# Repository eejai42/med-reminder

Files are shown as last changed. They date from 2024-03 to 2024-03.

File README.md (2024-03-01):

# Physical Med Reminder

The Physical Med Reminder is a novel, Arduino-assisted pillbox solution crafted to simplify the management of a twice-daily medication schedule without necessitating a complex user interface. This intuitive device is designed to learn the user's medication times through their actions, making it an ideal choice for individuals looking for an efficient and user-friendly medication management system.

## Project Overview

- **Name:** physical-med-reminder
- **Description:** A user-friendly, Arduino-assisted physical pillbox that manages a twice-daily medication schedule. It learns the user's medication times based on their initial actions after power-up, eliminating the need for a complex user interface.
- **Usage:**
  - **Box 1:** For Monday morning through Thursday morning doses.
  - **Box 2:** For Thursday evening through Sunday evening doses.
  - **Setting Reminder Times:** Plug in the device and take medication as normal to set the reminder schedule.

## Rules and Operation

### Setup

- The pillbox is organized to support a twice-daily medication regimen. Each compartment corresponds to a specific day and time (morning/evening).
- Magnets are placed in the compartments to track medication intake.

### Interaction

- The Arduino system signals when it's time to take medication through audible reminders. These reminders escalate in urgency until the medication is taken.
- The system learns the medication schedule based on user interaction after initial power-up. No further interaction is required unless there is a change in the medication schedule.

### Management

- Designed for easy setup, users fill each compartment according to their medication schedule at the beginning of the week.
- A power supply from a wall adapter ensures consistent operation, while the Arduino's internal clock maintains the time.
- To reset the schedule in the event of a power outage or medication time change, unplug the device, plug it back in, and take the pills as normal.

### Error Handling

- The device confirms learning the medication times through audible signals. Error handling informs the user of successful setup or any issues detected.

## Getting Started

This section will guide you through the initial setup and use of your Physical Med Reminder:

1. **Plug in the device** to a power source using the wall adapter.
2. **Fill the compartments** according to your weekly medication schedule. Ensure Box 1 is for morning doses (Monday to Thursday) and Box 2 for evening doses (Thursday to Sunday).
3. **Take your medication** at the usual times. The device will learn and remember these times as your medication schedule.
4. **Listen for reminders.** The device will alert you with audible reminders when it's time for your next dose.

## Support and Maintenance

For any questions, troubleshooting, or support needs, please refer to the user manual or contact our support team. Regular maintenance includes checking the power supply and ensuring the compartments are correctly filled at the start of each week.

## Conclusion

The Physical Med Reminder is more than just a pillbox; it's a comprehensive medication management system designed to adapt to your schedule, ensuring you never miss a dose again. With its simple setup and intuitive design, managing your medication has never been easier.

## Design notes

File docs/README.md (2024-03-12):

# Physical-Med-Reminder

## Project Overview

**Physical-Med-Reminder** is an innovative Arduino-assisted physical pillbox solution tailored to manage a twice-daily medication schedule efficiently. It stands out for its user-friendly design, eliminating the need for a complex interface by learning the user's medication times through their initial interactions. This project features two distinct pillboxes to cover a full week's medication regimen, leveraging Arduino technology for intelligent reminders and medication tracking.

### Description

This system is designed to simplify medication management without the need for constant reprogramming. Upon initial setup, the device learns the user's medication times based on their actions, setting up reminders accordingly. It employs a mechanical design with two separate units, each divided into seven compartments for a week's worth of medication, facilitating a straightforward morning and evening medication regimen.

### Usage

- **Box 1** is designated for Monday morning through Thursday morning doses.
- **Box 2** is used for Thursday evening through Sunday evening doses.
- Users set the reminder times by plugging in the device and taking their medication as usual. The device then schedules reminders based on these actions.

## Technical Specifications

### Wheel Configuration Overview

The system comprises two wheels (pillboxes), each divided into seven slices corresponding to days and times when medications need to be taken. These slices are equipped with magnets whose arrangements (read by hall effect sensors) serve to uniquely identify each slice, facilitating the system's ability to determine the current position and, consequently, the specific medication due for dispensing.

### Arduino Pin Configuration

The Physical-Med-Reminder system utilizes several pins on the Arduino for connecting various components such as speakers, LEDs, Hall effect sensors, and latching switches. Below is the updated pin configuration based on the latest information provided:

[Wheel and Pin Configuration Details](WheelAndPins.md)

### Time Settings
- **Day_time** and **Eve_time**: The system records the time of the first medication taken during the day and evening as the set reminder times for subsequent doses. This adaptive timing mechanism allows the system to align with the user's personal routine, ensuring medication reminders are timely and relevant.

### Binary Slice Identification
Each slice within the wheels is encoded with a binary representation, facilitating the identification process through the hall effect sensors. This coding allows the Arduino to determine not only which day's medication is due but also whether it's the day or evening dose, based on the unique binary slice ID associated with each compartment.

- **Example**: A slice with a binary code of `[0, 0, 1]` signals a specific position within the wheel, distinct from `[1, 1, 1]`, which represents a different day/time slot.

The **Movement State Machine** for the Physical-Med-Reminder project orchestrates the detection and handling of the mechanical movement of the pillbox wheels. This machine ensures the system accurately tracks the user's interaction with the pillbox, adjusting the reminder schedule accordingly. Below is an expanded and detailed explanation of each state and its role within the system.

[Movement State Machine Details](FSM.md)

### Operational Insight
This configuration ensures the Physical-Med-Reminder system can accurately track and manage the dispensing of medications throughout the week. By leveraging the binary slice IDs and the differentiation between day and evening times, the system provides a user-friendly, intuitive solution for medication adherence, minimizing the need for manual setup or frequent interaction.

## Arduino Settings

This section details the technical configuration of the Arduino hardware used in the Physical-Med-Reminder system. Understanding these settings is crucial for developers or technical users who wish to modify or further develop the system.

### Debounce Configuration

- **Wheel Turn Debounce (150 ms):** Minimizes noise or false triggers when detecting wheel rotation. It ensures that only intentional movements are registered.
- **Quick Turn Threshold (300 ms):** Differentiates between quick successive turns and slower, deliberate turns, aiding in accurately determining user interaction with the device.
- **Debounce Delay (500 ms):** Applied to all Hall effect sensors to filter out electrical noise and ensure stable readings.

### Timing

The med-reminder tracks only it's on start time, and the two pill times relative to that start time.  The actual time of day is not tracked.

[Timing Settings](Timing.md)

The **Technical Details** section outlines the hardware components and their functionalities within the Physical-Med-Reminder system. This system employs a blend of hall effect sensors, magnets, and a speaker to create a user-friendly medication management tool. Below, we delve into each component's role and how they integrate to form the operational backbone of the pillbox.

### Hardware Configuration

#### Hall Effect Sensors
- **Quantity**: 4
- **Functionality**: Hall effect sensors are crucial for detecting the presence of magnets in the pillbox slots. These sensors allow the system to identify which slot is currently positioned for dispensing medication. By reading the unique magnet configurations assigned to each slot, the system accurately tracks the user's medication schedule. This feature is key to the system's ability to learn and adapt to the user's medication-taking habits, ensuring timely reminders without the need for manual schedule inputs.

#### Magnets

- **Quantity**: 25
- 
- **Functionality**: Magnets are embedded within the pillbox slots, each arranged in a unique configuration to correspond with a specific day and time of medication. This arrangement enables the hall effect sensors to distinguish between the different slots and, by extension, the specific times medication needs to be taken. The strategic placement of these magnets is essential for the accurate identification of slots, allowing for an automated tracking system that adjusts to the user's medication regimen.

#### Speaker

- **Quantity**: 1

- **Functionality**: The speaker serves as the primary interface for auditory communication with the user. It is programmed to emit different patterns of sounds based on the system's status or required user actions. For instance:

  - **Medication Reminder**: A distinct sound pattern is played when it's time for the user to take their medication, serving as an effective reminder.
  
  - **Slot Not Advanced Warning**: If the system detects that the medication has not been taken following a reminder (i.e., the box has not been advanced to the next slot), it emits a different sound pattern to alert the user.

### Operational Integration

- **Slot Identification**: Combining the use of hall effect sensors and magnets, the system can pinpoint exactly which slot of the pillbox is ready for the user to access. This identification process is vital for maintaining an accurate medication schedule, ensuring that users are reminded only when it's time to take their medication.

- **Audible Notifications**: The speaker's role in the system extends beyond mere reminders. It confirms successful interactions (e.g., when the user advances the pillbox to the next slot) and alerts to errors or missed medication times. This auditory feedback mechanism is designed to be intuitive, minimizing the learning curve for users and enhancing the system's usability.

The design of the Physical-Med-Reminder leverages these components to create a seamless and efficient medication management experience. By intelligently combining hardware elements with sophisticated programming, the system offers a reliable solution to the challenge of medication adherence, tailored to meet the needs of individuals with various schedules and lifestyles.

## Setup and Operation

### Initial Setup

1. Fill each compartment according to the medication schedule at the beginning of the week.
2. Plug in the device and proceed to take medication as normal to set the reminder schedule.

### Daily Use

- The device signals medication times through escalating audible reminders.
- Manual rotation of the pillbox's current slot is achieved through a central button, moving to the next scheduled dose.

## Error Handling

The system provides auditory signals to confirm successful learning of medication times. It is equipped to inform the user of successful setup or detect any issues, ensuring reliable medication management.

## Maintenance and Management

Designed for easy setup and minimal maintenance, the device requires only a weekly refill and occasional reset (in case of a power outage or schedule change) by unplugging and replugging the device, then taking

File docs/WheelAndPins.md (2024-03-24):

[Full Readme](README.md)

### Pin Configuration

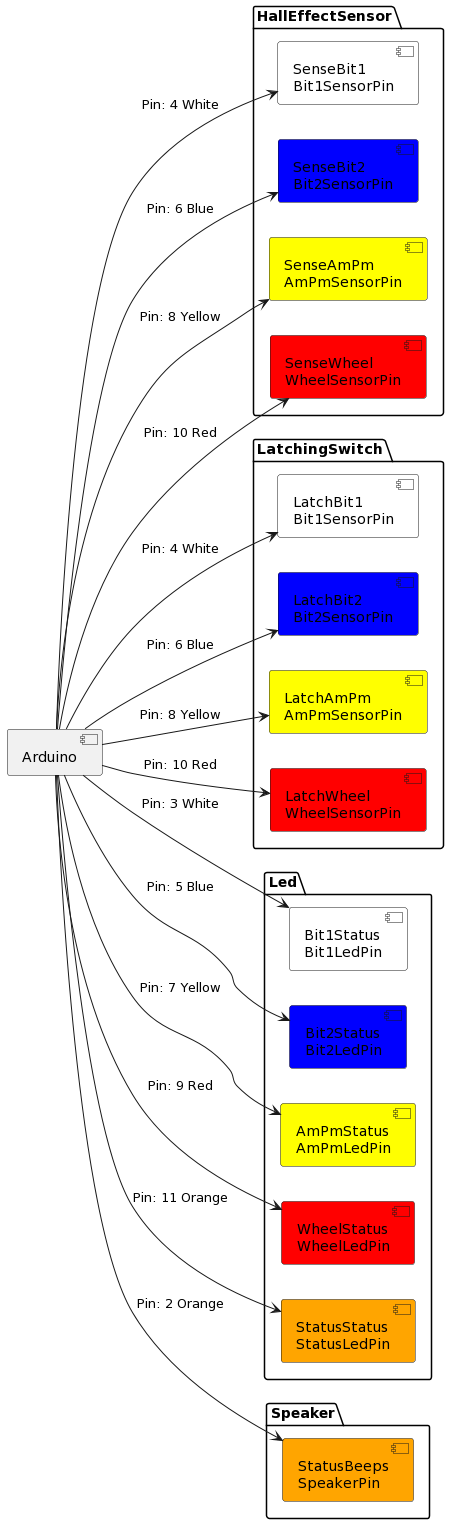
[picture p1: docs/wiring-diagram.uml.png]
Diagram


- **Speaker Pin (Pin 2)**: Utilized for status beep notifications, indicating reminders or alerts. Connected to a digital output pin on the Arduino.

#### LED Pins:
- **Bit1 Status LED (Pin 3)**: White LED for indicating Bit1 status.
- **Bit2 Status LED (Pin 5)**: Blue LED for indicating Bit2 status.
- **AM/PM Status LED (Pin 7)**: Yellow LED for differentiating between AM and PM doses.
- **Wheel Status LED (Pin 9)**: Red LED for showing the wheel's (pillbox) current position.
- **Status LED (Pin 11)**: Orange LED for general status indications.

#### Hall Effect Sensor Pins:
- **Bit1 Sensor (Pin 4)**: For sensing the position related to Bit1, utilizing two Hall effect sensors.
- **Bit2 Sensor (Pin 6)**: For sensing the position related to Bit2, also with two Hall effect sensors.
- **AM/PM Sensor (Pin 8)**: To determine the AM/PM slot, using two Hall effect sensors.
- **Wheel Sensor (Pin 10)**: For detecting the wheel's position, equipped with two Hall effect sensors.

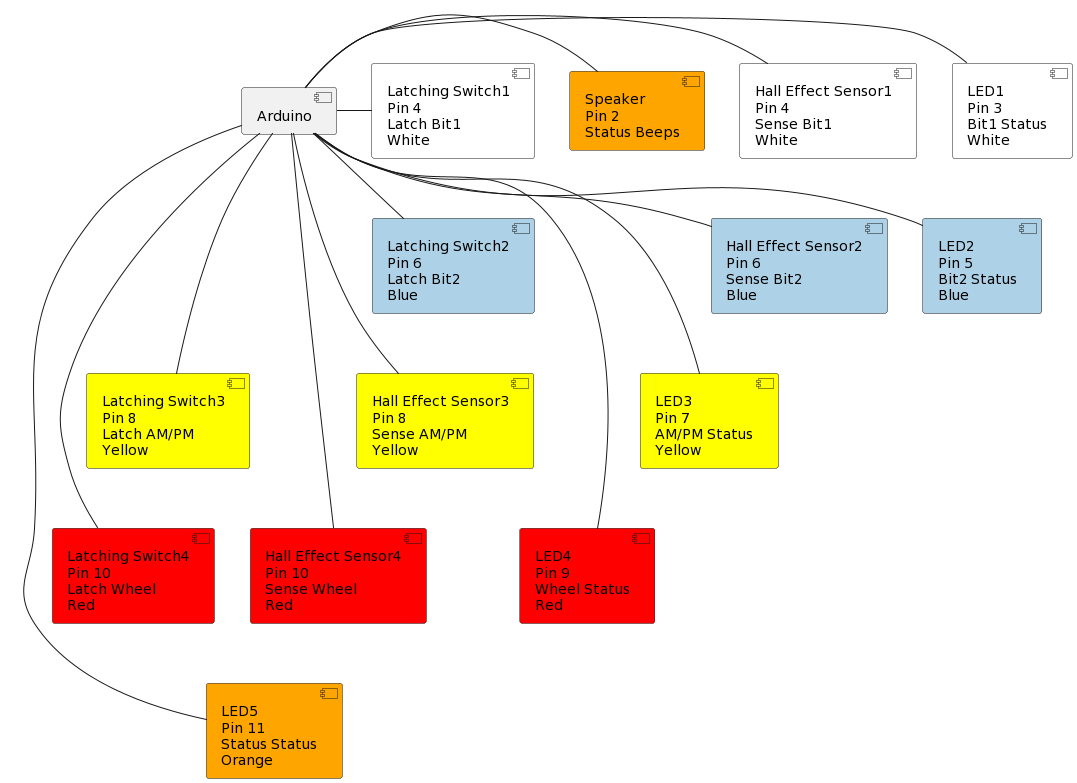
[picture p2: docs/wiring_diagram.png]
Wiring Diagram


### Wheel Details

The **Wheel Configurations** section provides detailed insights into how the Physical-Med-Reminder system organizes and identifies each compartment or "slice" of its two pillboxes, referred to as wheels. Each wheel is designed to accommodate a week's medication schedule, with unique identifiers for time of day (morning or evening) and specific days of the week. This structure is pivotal for the system's operation, ensuring precise medication dispensing and adherence to the user's schedule.

#### Wheel 1
- **Intended Use**: Covers Monday morning through Thursday morning doses.
- **Configuration**:
  - **Slices**: Each slice is designated for a specific day and either "Day" or "Eve" (evening) medication.
  - **Pill IDs**: Assigned from 1 to 7, correlating with each compartment's intended medication.
  - **Binary Slice ID**: A three-digit binary code unique to each slice, allowing the system to recognize the current compartment via hall effect sensors.

#### Wheel 2
- **Intended Use**: Utilized for Thursday evening through Sunday evening doses.
- **Configuration**:
  - The second wheel picks up where the first one leaves off, continuing with Thursday evening and ending with Sunday evening.
  - Similar to Wheel 1, each slice has a unique Pill ID and a binary code identifier. However, Wheel 2 has a distinguishing feature: a wheel sensor activated (marked as `true`) to differentiate its slices from those of Wheel 1.

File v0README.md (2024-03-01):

# Med-Reminder

Med-Reminder is a comprehensive medication reminder app for Android and iOS that helps users to never miss their medications. The app comes with unique features which include setting multiple reminders per day, a decaying back-off system that increases urgency and decreases frequency, and marking reminders as taken.

## Rules

- Set multiple reminders per day, must be marked as taken
- Unique decaying back-off system, increasing urgency, decreasing frequency
- Single quiet beep for initial reminder, auto-snooze for 10 seconds
- Initial reminder gentle, w/ increasing intensity after subsequent auto-snoozes.
- Gradually louder, but less frequent beeps following Fibonacci sequence
- Reminders not marked as 'taken' auto-snoozed
- Reminder skipped even if pill intake marked early

### Use Case 1

Imagine a person who needs to take medication every six hours. They set the first reminder for 8 am and mark it as taken. At 11 am, the second reminder goes off, and they take their pills, marking it as taken. However, at 2 pm, the third reminder goes off, but they forget to take their pills. The app auto-snoozes the reminder but then rings again after a short while, with a slightly louder beep. This continues until the user marks the reminder as "taken," ensuring that they don't miss a dose.

### Use Case 2

Consider a person who takes several medications at different times of the day. They set reminders for each of their medications, and the app reminds them accordingly. If they forget to mark a reminder as "taken," the app auto-snoozes it and reminds them again later with gradually louder and less frequent beeps, ensuring that they take all their medications on time.

## Conclusion

The Med-Alarm app ensures that users never miss taking their medications by providing multiple reminders and using a decaying back-off system that increases urgency and decreases frequency. The app also helps users keep track of their medication intake by allowing them to mark reminders as "taken." These rules help users stay on top of their medication schedules and improve their health outcomes.

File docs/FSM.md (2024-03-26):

[Full Readme](README.md)

### Movement State Machine (FSM)

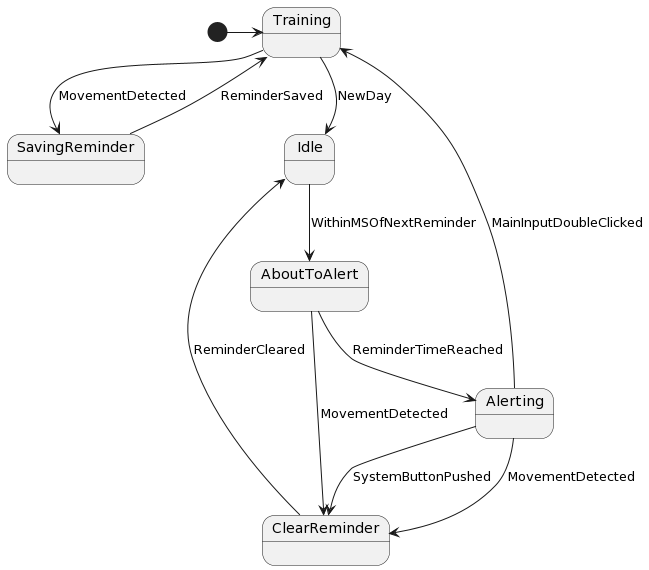
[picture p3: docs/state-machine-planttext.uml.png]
Diagram


### States and Transitions

#### 1. Training
First day - it just counts when pills are taken

 - **`Training .`**_`MovementDetected`_**`( ➡ SavingReminder )`:** 
 <span style="font-size: 1em; margin-bottom: 0.75em; color: green;">On training day, movement saves the reminder.<br /> <span>
 - **`Training .`**_`NewDay`_**`( ➡ Idle )`:** 
 <span style="font-size: 1em; margin-bottom: 0.75em; color: green;">When the first 24 hours is reached, the system stops training, and moves into the idle state.<br /> <span>
---------
 - **`SavingReminder .`**_`ReminderSaved`_**`( this )`:** 
 <span style="font-size: 0.8em; padding-bottom: 0.25em; color: darkgray;">On training day, the reminder is saved, and returns to Training.<span>
 - **`Alerting .`**_`MainInputDoubleClicked`_**`( this )`:** 
 <span style="font-size: 0.8em; padding-bottom: 0.25em; color: darkgray;">If the button is ever double  licked, reset the box<span>

#### 2. SavingReminder
When movement is detected during the first day, the reminder time is saved (relative to when the device was turned on)

 - **`SavingReminder .`**_`ReminderSaved`_**`( ➡ Training )`:** 
 <span style="font-size: 1em; margin-bottom: 0.75em; color: green;">On training day, the reminder is saved, and returns to Training..<br /> <span>
---------
 - **`Training .`**_`MovementDetected`_**`( this )`:** 
 <span style="font-size: 0.8em; padding-bottom: 0.25em; color: darkgray;">On training day, movement saves the reminder<span>

#### 3. Idle
This is the state that the device will spend most of it's time in, after training, but not while in the brief reminding/alerting phases.

 - **`Idle .`**_`WithinMSOfNextReminder`_**`( ➡ AboutToAlert )`:** 
 <span style="font-size: 1em; margin-bottom: 0.75em; color: green;">Within, say, a configurable 10 minutes of the reminder, it will switch to an about to alert state, where it is not yet alerting, but will count any movement to clear the pills.<br /> <span>
---------
 - **`Training .`**_`NewDay`_**`( this )`:** 
 <span style="font-size: 0.8em; padding-bottom: 0.25em; color: darkgray;">When the first 24 hours is reached, the system stops training, and moves into the idle state<span>
 - **`ClearReminder .`**_`ReminderCleared`_**`( this )`:** 
 <span style="font-size: 0.8em; padding-bottom: 0.25em; color: darkgray;">After the appropriate reminder has been cleared, go back to the idle state.<span>

#### 4. AboutToAlert
When we are within a little bit of time of the reminder, any movement detected will clear the next reminder, but it will not start actively alerting yet

 - **`AboutToAlert .`**_`ReminderTimeReached`_**`( ➡ Alerting )`:** 
 <span style="font-size: 1em; margin-bottom: 0.75em; color: green;">If we are about  to alert, and the reminder time is reached, start alerting..<br /> <span>
 - **`AboutToAlert .`**_`MovementDetected`_**`( ➡ ClearReminder )`:** 
 <span style="font-size: 1em; margin-bottom: 0.75em; color: green;">Movement in the about to alert state will move to clear the appropriate reminder..<br /> <span>
---------
 - **`Idle .`**_`WithinMSOfNextReminder`_**`( this )`:** 
 <span style="font-size: 0.8em; padding-bottom: 0.25em; color: darkgray;">Within, say, a configurable 10 minutes of the reminder, it will switch to an about to alert state, where it is not yet alerting, but will count any movement to clear the pills<span>

#### 5. Alerting
When the actual alerting time is reached, it starts alerting.

 - **`Alerting .`**_`MainInputDoubleClicked`_**`( ➡ Training )`:** 
 <span style="font-size: 1em; margin-bottom: 0.75em; color: green;">If the button is ever double  licked, reset the box.<br /> <span>
 - **`Alerting .`**_`SystemButtonPushed`_**`( ➡ ClearReminder )`:** 
 <span style="font-size: 1em; margin-bottom: 0.75em; color: green;">While alerting, if the system button is pushed, move to clear the reminder..<br /> <span>
 - **`Alerting .`**_`MovementDetected`_**`( ➡ ClearReminder )`:** 
 <span style="font-size: 1em; margin-bottom: 0.75em; color: green;">While alerting, if movement is detected, go to clear the reminder..<br /> <span>
---------
 - **`AboutToAlert .`**_`ReminderTimeReached`_**`( this )`:** 
 <span style="font-size: 0.8em; padding-bottom: 0.25em; color: darkgray;">If we are about  to alert, and the reminder time is reached, start alerting.<span>

#### 6. ClearReminder
In a variety of situations, 

 - **`ClearReminder .`**_`ReminderCleared`_**`( ➡ Idle )`:** 
 <span style="font-size: 1em; margin-bottom: 0.75em; color: green;">After the appropriate reminder has been cleared, go back to the idle state..<br /> <span>
---------
 - **`AboutToAlert .`**_`MovementDetected`_**`( this )`:** 
 <span style="font-size: 0.8em; padding-bottom: 0.25em; color: darkgray;">Movement in the about to alert state will move to clear the appropriate reminder.<span>
 - **`Alerting .`**_`SystemButtonPushed`_**`( this )`:** 
 <span style="font-size: 0.8em; padding-bottom: 0.25em; color: darkgray;">While alerting, if the system button is pushed, move to clear the reminder.<span>
 - **`Alerting .`**_`MovementDetected`_**`( this )`:** 
 <span style="font-size: 0.8em; padding-bottom: 0.25em; color: darkgray;">While alerting, if movement is detected, go to clear the reminder.<span>

### Initial State
- **Idle**: The machine initializes in the Idle state, awaiting the first user interaction to begin the detection and handling process.

### Implementation Note
This state machine is crucial for ensuring the pillbox operates reliably, accurately tracking user interactions to maintain an up-to-date medication schedule. It effectively filters out accidental or irrelevant movements, focusing on intentional user actions to adjust the medication reminder timings. Through this mechanism, the Physical-Med-Reminder system provides a user-friendly and intuitive interface that requires minimal direct interaction, simplifying daily medication management.

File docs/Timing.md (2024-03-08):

# [Full Readme](README.md)

### Timing Configurations

- **Minutes Per Day (1440):** This parameter represents the number of minutes in a standard day, aligning with the real-world time system. It's utilized for synchronizing the system's internal clock with the actual time, facilitating accurate schedule management and timing operations.

- **Milliseconds Per Minute (60000):** Defines the length of one minute in milliseconds. This setting is crucial for converting the system's time calculations into real-time operations, ensuring the timing functionalities like reminders are executed with precision.

### Reminder Settings

- **Initial Reminder Delay (2 seconds):** Specifies the delay before the first reminder beep is emitted after a scheduled reminder time is reached. This short interval allows for immediate notification with a brief pause to avoid startling the user.

- **Initial Times to Beep (5):** Indicates how many times the system will beep during the initial reminder. This feature is designed to attract the user's attention effectively, ensuring they are aware of the need to take their medication.

- **Milliseconds Between Beeps (85):** The duration between consecutive beeps in a reminder sequence. This timing is optimized to make the reminder audible and noticeable without being annoying, striking a balance between alertness and comfort for the user.

These settings are integral to the functionality of the Physical-Med-Reminder system, providing a reliable and user-friendly platform for medication management. Developers have the flexibility to modify these parameters according to specific requirements, enabling customization for varying reminder needs or operational preferences.

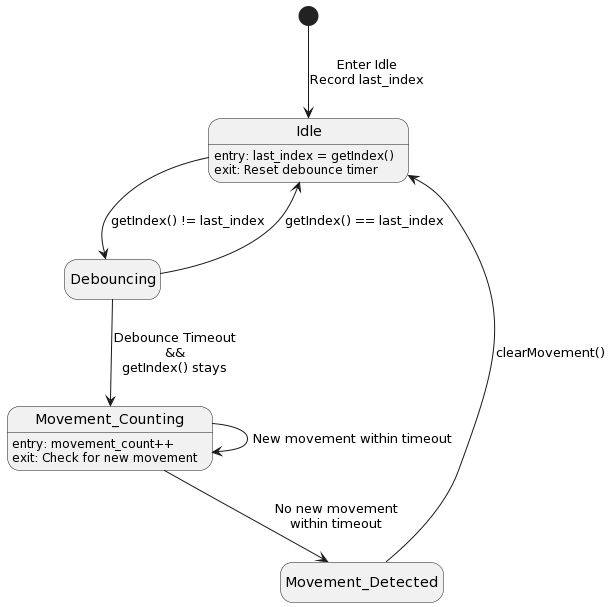
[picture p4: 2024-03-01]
arduino/sketch1/docs/flowchart.png

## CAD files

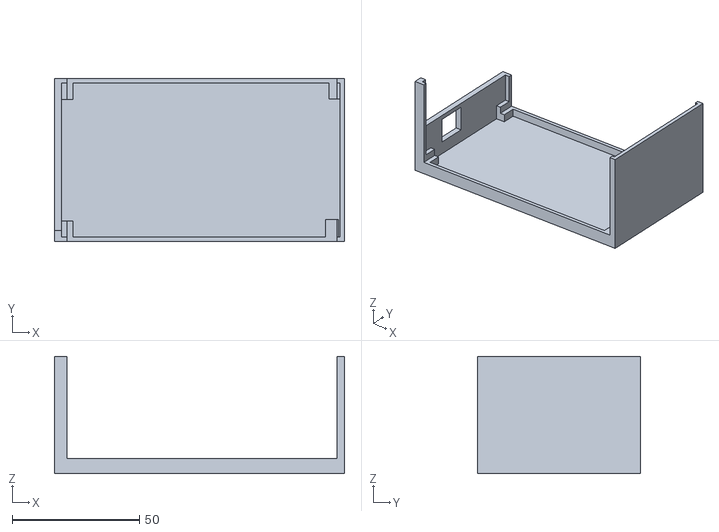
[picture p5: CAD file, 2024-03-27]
CarrierBox/box_v9_no_lid.stl
114.0 x 64.0 x 46.0

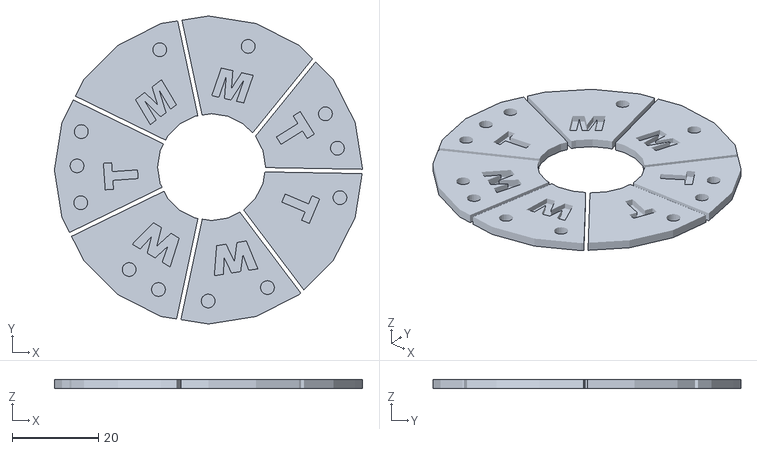
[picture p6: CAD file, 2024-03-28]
PillBoxInserts/InsertTestSlice_v5_7pc.stl
71.3 x 71.2 x 2.00

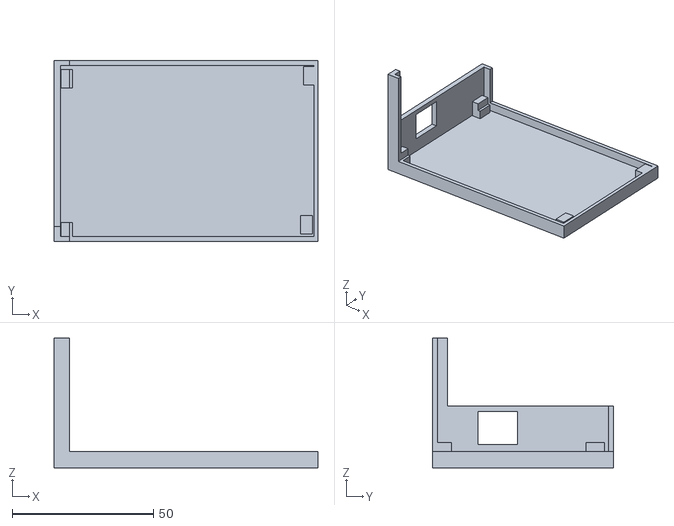
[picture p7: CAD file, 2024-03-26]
CarrierBox/Super Jaiks.stl
93.5 x 64.0 x 46.0

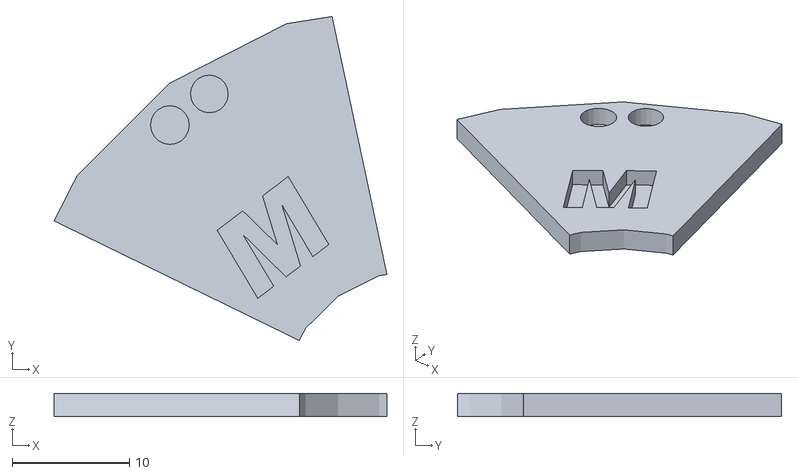
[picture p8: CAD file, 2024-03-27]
PillBoxInserts/InsertTestSlice_v4_1pc.stl
28.3 x 27.6 x 2.00

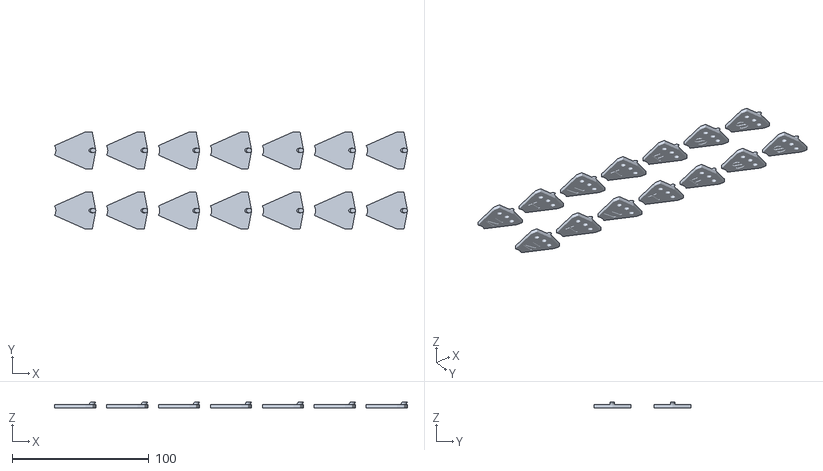
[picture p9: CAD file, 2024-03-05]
PillBoxInserts/InsertSlicesv21_14pc.stl
258.3 x 71.2 x 4.38

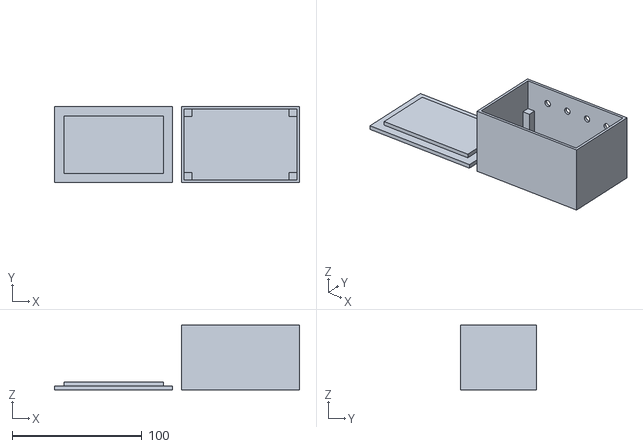
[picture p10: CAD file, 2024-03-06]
CarrierBox/box_v1.stl
189.0 x 59.0 x 50.0

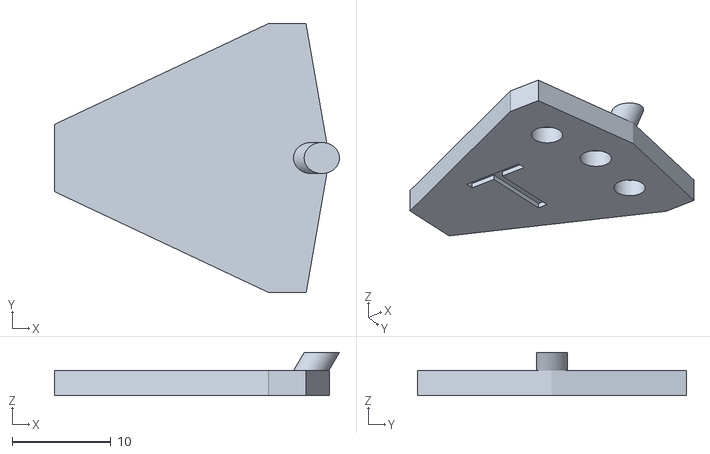
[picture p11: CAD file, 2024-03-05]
PillBoxInserts/InsertSlicesv17_1pc.stl
28.8 x 27.2 x 4.38

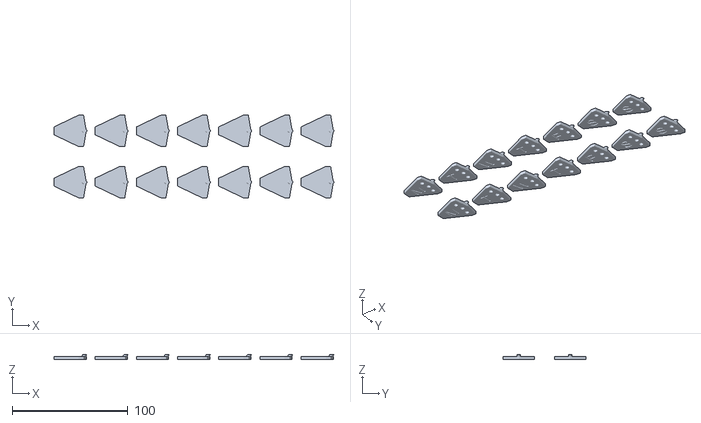
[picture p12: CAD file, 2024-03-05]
PillBoxInserts/InsertSlicesv19_14pc.stl
241.9 x 71.5 x 4.38

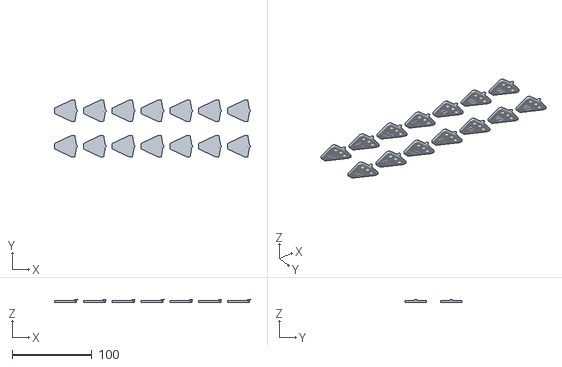
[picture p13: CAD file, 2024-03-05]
PillBoxInserts/InsertSlicesv18_14pc.stl
245.4 x 71.5 x 4.38

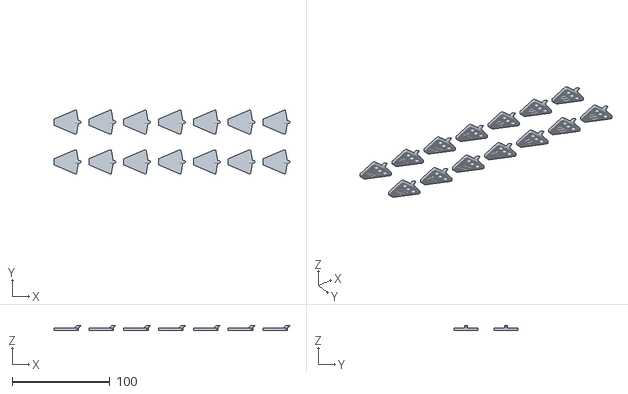
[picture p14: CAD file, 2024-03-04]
PillBoxInserts/InsertSlicesv15_14pcs.stl
241.0 x 64.9 x 5.08

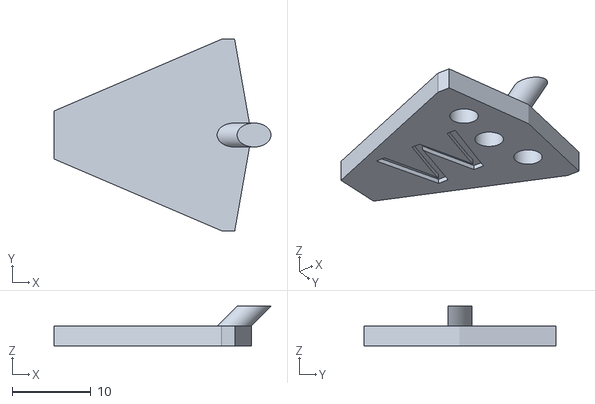
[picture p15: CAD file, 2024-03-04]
PillBoxInserts/InsertSlicesv16_1pc.stl
27.6 x 24.4 x 5.08

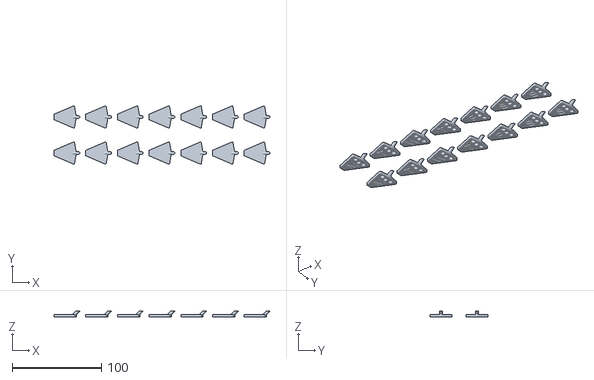
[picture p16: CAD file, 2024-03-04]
PillBoxInserts/InsertSlicesv14.stl
242.4 x 64.9 x 6.35

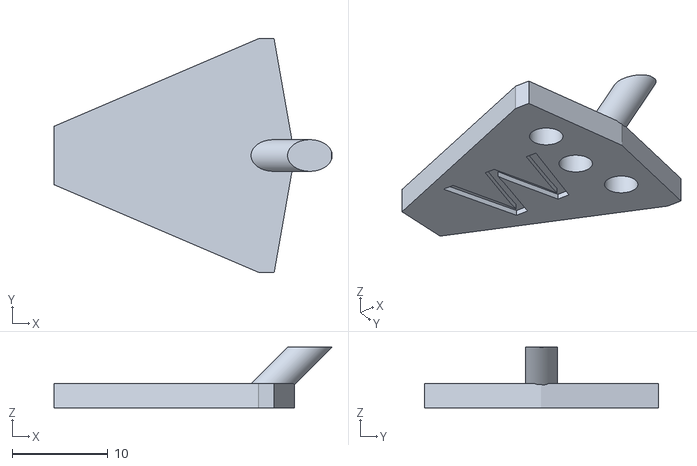
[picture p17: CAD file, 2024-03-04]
PillBoxInserts/InsertSlicesv15_1pc.stl
29.0 x 24.4 x 6.35

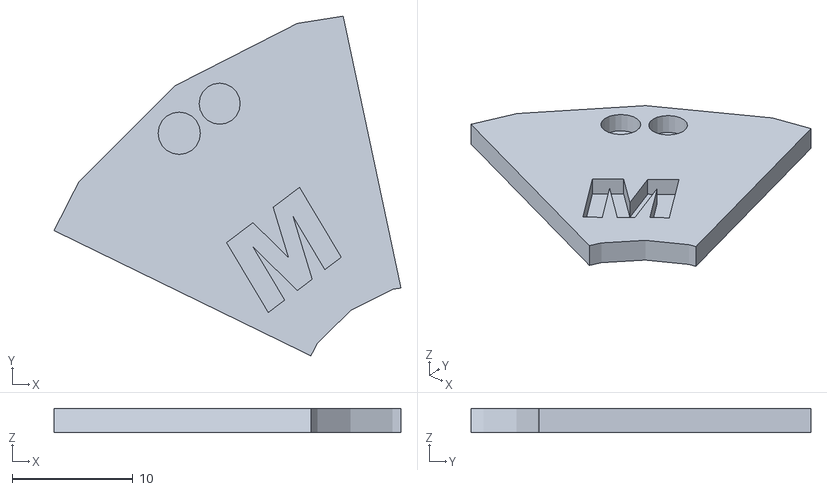
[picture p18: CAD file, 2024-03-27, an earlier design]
PillBoxInserts/InsertTestSlice_v3_1pc.stl
28.8 x 28.1 x 2.00

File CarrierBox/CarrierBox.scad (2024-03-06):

// Credit Card Box Dimensions
BOX_LENGTH = 89;
BOX_WIDTH = 61;
BOX_HEIGHT = 75;
WALL_THICKNESS = 1;
HOVER_GAP = 5;
LID_THICKNESS = 1;
INSET_WIDTH = 1;
INSET_HEIGHT = 2;
INSET_GAP = 10.5;

 // Adding posts in each corner
// Post dimensions
POST_SIZE = 3;
POST_WIDTH = POST_SIZE;
POST_DEPTH = POST_SIZE;
POST_HEIGHT = BOX_HEIGHT / 2;

// Lid Clearance
LID_CLEARANCE = 0.2; // Small gap for easy lid fitting
LID_HEIGHT = 5; // Height of the lid

// New constants for drilling holes
HOLE_DIAMETER = 5; // Diameter of each hole
HOLE_Y_DISTANCE = BOX_HEIGHT - (BOX_HEIGHT / 4); // Distance of holes from the base of the box

// USB details
USB_HEIGHT = BOX_HEIGHT / 10;
USB_WIDTH = BOX_WIDTH / 5;
USB_X_OFFSET = (BOX_WIDTH / 5);
USB_Y_OFFSET = (POST_HEIGHT) - (USB_HEIGHT * 1 + (USB_HEIGHT / 3));

// Function to create the main box
module box() {
    difference() {
        // Outer dimensions
        cube([BOX_LENGTH + 2*WALL_THICKNESS, BOX_WIDTH + 2*WALL_THICKNESS, BOX_HEIGHT]);
        // Inner cavity
        translate([WALL_THICKNESS, WALL_THICKNESS, WALL_THICKNESS])
        cube([BOX_LENGTH, BOX_WIDTH, BOX_HEIGHT + WALL_THICKNESS]); // Extend inner cavity into the lid area for a flush fit
    }
    
      
    // Bottom left front post
    translate([WALL_THICKNESS, WALL_THICKNESS, WALL_THICKNESS])
    cube([POST_WIDTH, POST_DEPTH, POST_HEIGHT]);
    
    // Bottom right front post
    translate([BOX_LENGTH + WALL_THICKNESS - POST_WIDTH, WALL_THICKNESS, WALL_THICKNESS])
    cube([POST_WIDTH, POST_DEPTH, POST_HEIGHT]);
    
    // Bottom left back post
    translate([WALL_THICKNESS, BOX_WIDTH + WALL_THICKNESS - POST_DEPTH, WALL_THICKNESS])
    cube([POST_WIDTH, POST_DEPTH, POST_HEIGHT]);
    
    // Bottom right back post
    translate([BOX_LENGTH + WALL_THICKNESS - POST_WIDTH, BOX_WIDTH + WALL_THICKNESS - POST_DEPTH, WALL_THICKNESS])
    cube([POST_WIDTH, POST_DEPTH, POST_HEIGHT]);
}

// Function to drill holes into the long side of the box
module drillHoles() {
    for(i = [1:4]) {
        translate([
            WALL_THICKNESS + (BOX_LENGTH - (3 * HOLE_DIAMETER)) * i / 4, // Evenly space along the length, adjusting for hole diameter
            BOX_WIDTH + 2*WALL_THICKNESS + 1, // Position to drill through the wall thickness
            HOLE_Y_DISTANCE
        ])
        rotate([90, 0, 0])
        cylinder(d = HOLE_DIAMETER, h = WALL_THICKNESS * 2, $fn=50);
    }
    
    translate([-1, USB_X_OFFSET, USB_Y_OFFSET]) {
        rotate([0, 0, 0])
        cube([WALL_THICKNESS * 3, USB_WIDTH, USB_HEIGHT]);
    }
}

// Function to create the box with holes
module boxWithHoles() {
    difference() 
    {
        // Original box design
        box();
        // Drill holes
        drillHoles();
    }
}

// Updated function to create the lid with an inset
module lid() {
    // Outer lid
    translate([0, 0, BOX_HEIGHT + HOVER_GAP])
    cube([BOX_LENGTH + 2*LID_THICKNESS, BOX_WIDTH + 2*LID_THICKNESS, LID_THICKNESS]);

    // Inset for the lid to fit into the box
//    translate([WALL_THICKNESS + floor(INSET_GAP/2), WALL_THICKNESS + floor(INSET_GAP/2), BOX_HEIGHT + HOVER_GAP + (LID_THICKNESS * -1)])
    translate([WALL_THICKNESS * 2, WALL_THICKNESS * 2, BOX_HEIGHT + HOVER_GAP + (LID_THICKNESS * -1)])
    color("red")
    cube([(BOX_LENGTH - (WALL_THICKNESS * 2)), BOX_WIDTH - (WALL_THICKNESS * 2), LID_THICKNESS]);
}

module rotateLid() {
    translate([-(LID_THICKNESS + HOVER_GAP), 0, BOX_HEIGHT + (LID_THICKNESS * 6)])
    rotate([0, 180, 0])
    lid();
}

// Rendering the box and lid
boxWithHoles();
//rotateLid();

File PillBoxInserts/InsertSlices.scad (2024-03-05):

$fn = 100; // Increase for smoother curves
inch_to_mm_conversion_factor = 25.4;
crust_height = 1.3 * inch_to_mm_conversion_factor; // Slice length from tip to crust in mm
slice_length = (1.4 * inch_to_mm_conversion_factor) - 1; // Crust height in mm
thickness = 0.10 * inch_to_mm_conversion_factor; // Thickness of the slice in mm
bite_size = slice_length/5;
cylinder_height = thickness * 5; // Height of the cylinder
cylinder_diameter = thickness * 1.2; // Diameter of the cylinder

hole_diameter = 3.25;

function calculateSlicePoints(slice_length, crust_height) = 
    let(half_base = crust_height / 2)
    [
        [0, 0], // Tip of the slice
        [slice_length, half_base], // Right crust edge
        [slice_length, -half_base] // Left crust edge
    ];


// Pizza slice footprint with dynamically calculated points
module pizzaSliceFootprint() {
    color("blue") 
    polygon(points=calculateSlicePoints(slice_length, crust_height));    
}

// Clipping cube to trim the pizza slice tip
module clippingCube() {
    trim_factor = 10;
    slant1 = 1.6233;
    slant2 = -5;
    
    translate([0, -crust_height, -1]) 
    color("red")
    cube([bite_size, crust_height * 2, thickness * 2]);
    
    translate([1,0, 1]) {
        color("red");
        cylinder(h = thickness * 5, r = bite_size, center = true);
    }


        
    translate([crust_height * slant1, -(crust_height / 2) + (crust_height / trim_factor), -1]) 
    rotate([0, 0, 100])
    color("orange")
    cube([100, crust_height / 2, 5]);

    translate([crust_height - slant2, (crust_height / 2) + (crust_height / trim_factor), -1]) 
    rotate([0, 0, -100])
    color("orange")
    cube([100, crust_height / 2, 5]);

    translate([0, -(crust_height) + (crust_height / trim_factor), -1]) 
    color("blue")
    cube([100, crust_height / 2, 5]);

    translate([0, (crust_height / 2) - (crust_height / trim_factor), -1]) 
    color("blue")
    cube([100, crust_height / 2, 5]);
}

// Extruding the footprint to create the slice with clipping effect
module pizzaSliceWithClipping() {
    difference() 
    {
        linear_extrude(height = thickness) {
            pizzaSliceFootprint();
        }
        clippingCube();
    }
}

// Adding the cylinder on the crust as a handle
module cylinderOnCrust() {
    x_offset = 2.6;
    // Translate and rotate the cylinder to position it like a handle
    translate([slice_length - x_offset, 0, 3]) // Adjust for correct placement
    rotate([0, 30, 0]) // Tilted 45 degrees to intersect the crust
    cylinder(h = cylinder_height, d = cylinder_diameter, $fn = $fn, center = true);
}

module cylinderOnCrustWithClipping() {
    difference()
    {
        cylinderOnCrust();
        cylinderClippingCube();
    }
}

module cylinderClippingCube() {
    clipping_cube_height = 2;
    top_offset = -0.7;
    translate([0, -crust_height, -thickness * clipping_cube_height]) // bottom cut
    color("red")
    cube([slice_length * 2, crust_height * 2, thickness * clipping_cube_height]);
    
    translate([0, -crust_height, thickness * clipping_cube_height + top_offset]) 
    color("blue")
    cube([slice_length * 2, crust_height * 2, (thickness * clipping_cube_height)]); // top cut
}

// Main module to render the final slice with all components
module finalSlice() {
    pizzaSliceWithClipping(); // Render the pizza slice with the clipping effect
    cylinderOnCrustWithClipping(); // Add the cylinder handle
}

// Render the final pizza slice
//finalSlice();

module drillHoles() {
    depth = -0.25;
    x0_translation = -0;
    x1_translation = 1;
    x2_translation = -0;
    y_offset = 7;
    
    translate([slice_length - (slice_length / 5) + x0_translation, y_offset, -thickness * depth]) // Adjust for correct 
    cylinder(h = thickness, d = hole_diameter, $fn = $fn, center = true);

    translate([slice_length - (slice_length / 5) + x1_translation, 0, -thickness * depth]) // Adjust for correct placement
    cylinder(h = thickness, d = hole_diameter, $fn = $fn, center = true);

    translate([slice_length - (slice_length / 5) + x0_translation, -y_offset, -thickness * depth]) // Adjust for correct 
    cylinder(h = thickness, d = hole_diameter, $fn = $fn, center = true);
}


module finalSliceWithText(slice_text, text_line_2, day_num, day) {
    colorToSet = day ? "#0F0FaF" : "white";
    color(colorToSet)
    scale([1.10, 1.025, 1]) {
        x_translation = ((day_num * slice_length) + 5) - ((slice_length * 8) / 2);    
        //text_line_2 = "foo";
        slice_text = slice_text[0];
        y_translation = (crust_height / 2) + 5;
        echo(text_line_2)
        if (day) {
            echo("UPDATING y TRANSLATION");
            y_translation = -y_translation;
            translate([x_translation, y_translation, 0]) {
                difference() 
                {
                    {
                        finalSlice();
                        writetext(slice_text, text_line_2);
                    }
                    drillHoles();
                }
            }
        } else {
            translate([x_translation, y_translation, 0]) {
                difference() 
                {
                    {
                        finalSlice();
                        writetext(slice_text, text_line_2);
                    }
                    drillHoles();
                }
            }
        }
    }
}



module writetext(text, text_line_2) {
    // assuming default text size and font, adjust as needed
    font_size = thickness * 3.5;
    left = (slice_length / 1.9);
    top = (font_size / 2) + 1;
    line2top = top + font_size - 1;
    depth = -thickness - 2;
    translate([0, 0, depth]) {
        linear_extrude(thickness * 2) {// adjust the height to match the desired depth of the text engraving
            color("blue")
            translate([left, top - 1, 0]) {
                rotate([180, 0, 0])
                text(text, size = font_size, halign = "center", valign = "bottom"); // adjust text size and alignment as needed
            }
            
//            translate([left, line2top, 0]) {
//                rotate([180, 0, 0])
//                text(text_line_2, size = font_size, halign = "center", valign = "bottom"); // adjust text size and alignment as needed
//            }
        }
    }
}

// Example usage of finalSliceWithText

//translate([-4.2,21.8, 0]) 
{
    finalSliceWithText("Mon", "+", 1, true);
    finalSliceWithText("Tue", "+", 2, true);
    finalSliceWithText("Wed", "+", 3, true);
    finalSliceWithText("Thu", "+", 4, true);
    finalSliceWithText("Fri", "+", 5, true);
    finalSliceWithText("Sat", "+", 6, true);
    finalSliceWithText("Sun", "+", 7, true);
    finalSliceWithText("Mon", "-", 1, false);
    finalSliceWithText("Tue", "-", 2, false);
    finalSliceWithText("Wed", "-", 3, false);
    finalSliceWithText("Thu", "-", 4, false);
    finalSliceWithText("Fri", "-", 5, false);
    finalSliceWithText("Sat", "-", 6, false);
    finalSliceWithText("Sun", "-", 7, false);
}

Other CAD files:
PillBoxInserts/InsertSlicesv20_14pc.stl
CarrierBox/box_v8_no_lid.stl
CarrierBox/box_v7_no_lid.stl
PillBoxInserts/InsertTestSlice_v2_1pc.stl
CarrierBox/box_v2_no_lid.stl
CarrierBox/box_v3_no_lid.stl
CarrierBox/box_v4_no_lid.stl
CarrierBox/box_v5_no_lid.stl
CarrierBox/box_v6_no_lid.stl
PillBoxInserts/InsertTestSlice_1pc.stl

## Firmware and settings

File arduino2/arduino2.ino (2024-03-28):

// main.cpp
#pragma once

#include <Arduino.h>
#include "MedReminderStateMachine.h"

MedReminderStateMachine* stateMachine;

void setup() {
  // Initialize serial communication at 9600 bits per second:
  Serial.begin(9600);
  stateMachine = new MedReminderStateMachine();
}

void loop() {
  stateMachine->checkState();
}

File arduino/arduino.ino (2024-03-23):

// main.cpp
#include "Arduino.h"
#include "constants.h"
#include "alarm_helpers.h"
#include "wheel_helpers.h"

void setup() {
  // Initialize serial communication at 9600 bits per second:
  Serial.begin(9600);
  setupAlarms(); // Initialize speaker pin
  setupWheel(); // Initialize wheel sensor pins
  simulateSetupTime(); // setup time.
}

void loop() {
  //Main loop code to check wheel movement, play beeps, and handle time reminders

  checkState();

  // Example: Detect and handle debounced wheel movement
  if (movementDetected()) {
     printAndClearMovement();
     triggerTimer();
  } 

  checkAlarms();
}

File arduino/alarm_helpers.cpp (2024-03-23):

#include "Arduino.h"
#include "constants.h"
#include "wheel_helpers.h"
#include "alarm_helpers.h"

// Timer states
unsigned long currentMinutes = 0;
bool is_am = false;
int initialDay = 0;
bool timer1IsAM = true;
int timer1OffsetMS = -1;
int timer1OffsetMinutes = -1;
unsigned long timer1 = -1;  // Minute mark for the second timer
unsigned long timer2 = -1;  // Minute mark for the second timer
int reminding = false;
int beepsBeeped = 0;
double timesToBeep = initial_times_to_beep;
double secondsBetweenReminders = initial_reminder_delay_seconds;
unsigned long remindersSnoozedAtMS = 0;
unsigned long timer2SetAt = 0;

unsigned long mymillis() {
  // if (timer1OffsetMS > 0) {
  //   Serial.println(" ADDING:  " + String(timer1OffsetMS) + " to mymillis()....");
  // }
  return millis() + timer1OffsetMS;
}

int getTimer2Minutes() {
  return timer2;
}

int days_into_cycle() {

  int dayNumber = (int)floor(mymillis() / msPerMinute / minutesPerDay) % 7;
  int currentDay = (initialDay + dayNumber) % 7;

  return currentDay;
}

DayTime getDayAndTime(bool isWheel1, int sliceIndex) {

  bool isWheel2 = !isWheel1;
  int localSlice = sliceIndex;

  DayTime result;
  result.isAM = is_am;
  result.dow = getIndex() % 7;
  result.system_day = days_into_cycle();
  result.system_minutes = minutes_since_day_started();
  result.timer2_minutes = getTimer2Minutes();
  return result;
}

bool getIsAM() {
  return is_am;
}

void setupAlarms() {
  pinMode(speakerPin, OUTPUT);
  pinMode(ledPin, OUTPUT);

  DayTime dt = getDayAndTime();
}

void startReminding() {
  if ((timer2SetAt > 0) && (timer2SetAt + 3000 > mymillis())) {
    // Serial.println("NOT STARTING REMINDER - TOO SOON AFTER REMINDER SET");
    // Serial.println(timer2SetAt);
    // Serial.println(mymillis());

    return;
  }

  reminding = true;
  beepsBeeped = 0;
  remindersSnoozedAtMS = 0;

  Serial.println();
  Serial.println();
  Serial.println("          ************   ALARM - ALARM - ALARM!!!! *********** ");
  if (getIsAM()) {
    Serial.print("          ************        ^ MORNING ^        *********** ");
  } else {
    Serial.print("          ************        V evening V        *********** ");
  }
  Serial.println(String(is_am ? "PILLBOX: DAY" : "PILLBOX: NIGHT") + " TIMERS: " + minutesToAMPMString(timer1) + " vs. " + minutesToAMPMString(timer1));
  Serial.println();
  Serial.println();
  printSystemTime();
}


void stopReminding() {
  if (reminding) {

    reminding = false;
    remindersSnoozedAtMS = 0;
    Serial.println();
    Serial.println("            *******************************");
    Serial.println("            ** Pills taken!! Nice work **!");
    Serial.println("Pills taken");
    Serial.println("            *******************************");
    Serial.println();
  }
}

void snooze() {
  // Serial.print("                                    Snoozing for seconds: ");
  // Serial.println(secondsBetweenReminders);
  remindersSnoozedAtMS = mymillis();
}

bool isSnoozed() {
  if (remindersSnoozedAtMS > 0) {
    int secondsSinceSnoozed = (mymillis() - remindersSnoozedAtMS) / 1000;
    if (secondsSinceSnoozed > secondsBetweenReminders) {
      //Serial.println("DONE beeping");
      beepsBeeped = 0;
      remindersSnoozedAtMS = 0;
    }
  }
  return remindersSnoozedAtMS > 0;
}

bool beepCountExceeded() {
  bool countExceeded = beepsBeeped > timesToBeep;
  return countExceeded;
}

void emitAlarmBeep() {
  //Serial.println("beeping");
  beep(msBetweenBeeps);
  beepsBeeped++;
}

void emitBeepsOrSnooze() {
  if (!isSnoozed()) {
    if (beepCountExceeded()) {
      snooze();
    } else {
      emitAlarmBeep();
    }
  }
}


void checkAlarmBeeping() {
  if (reminding) emitBeepsOrSnooze();
}

void checkAlarms() {
  return;
  if (timer1OffsetMS == -1) {
    //timer1IsAM = getIsAM();
    timer1OffsetMinutes = 0;  //timer1IsAM ? 0 : minutesPerDay / 2;
    timer1OffsetMS = 0;       // timer1IsAM ? 0 : timer1OffsetMinutes * msPerMinute;
    if (timer1OffsetMS > 0) {
      Serial.println("INCLUDING OFFSETS: ADDING " + String(timer1OffsetMinutes));
    }
  }

  unsigned long tempMinutes = minutes_since_day_started();
  if (tempMinutes != currentMinutes) {
    currentMinutes = tempMinutes;
    if ((mymillis() % 1000) < 10) {
      Serial.println();
      printSystemTime();
      printDowTod();
      Serial.println();
    }

    if ((currentMinutes == timer1) || (currentMinutes == timer2)) {
      startReminding();
    }
  } else {
    checkAlarmBeeping();
  }
}

unsigned long minutes_since_day_started() {
  return (mymillis() / msPerMinute) % minutesPerDay;  // Convert milliseconds to minutes
}

void checkTimers() {
  if (timer2 != -1) {
    unsigned long currentMinutes = minutes_since_day_started();

    if (currentMinutes == timer1) {
      Serial.println("Timer reached: time1 reached");
      // Ensure message is not repeated by unsetting or adjusting the condition
    }

    if (currentMinutes == timer2) {
      Serial.println("Timer2 reached: time1 reached");
      // Ensure message is not repeated by unsetting or adjusting the condition
    }
  }
}

void beep(int duration = 1000) {
  tone(speakerPin, 440, msBetweenBeeps * 2);
  digitalWrite(ledPin, HIGH);  // Turn the LED on (HIGH is the voltage level)
  delay(msBetweenBeeps);       // Wait for a second (1000 milliseconds)
  digitalWrite(ledPin, LOW);   // Turn the LED off by making the voltage LOW
  delay(msBetweenBeeps);       // Wait for a second (1000 milliseconds)
}

void printSetTimerMsg(String msg, int timer) {
  Serial.println();
  Serial.println("            *******************************");
  Serial.print("            ** ");
  Serial.print(msg);
  Serial.println(minutesToAMPMString(timer));
  Serial.println("            *******************************");
}

void triggerTimer() {
  unsigned long currentMinutes = minutes_since_day_started();
  DayTime dt = getDayAndTime();
  String finalSliceTOD = (dt.isAM && timer1IsAM) ? "Evening " : "Morning ";
  //Serial.println("_______ TRIGGER DETECTED __________");
  if (mymillis() > 10000) {
    if ((timer1 == -1)) {
      timer1 = currentMinutes;

      timer2SetAt = mymillis();
      printSetTimerMsg(finalSliceTOD + " Reminder Set For 00:", timer1);
    } else if (timer2 == -1) {

      timer2 = (timer1 != currentMinutes) ? currentMinutes : max(timer1 + 1, currentMinutes);
      timer2SetAt = mymillis();
      printSetTimerMsg(finalSliceTOD + " Reminder set for 00:", timer2);
      printDowTod();
    } else {
      Serial.println("setting reminding = false");
      stopReminding();
    }
  } else {
    clearMovement();
    initialDay = getIndex();
    Serial.println();
    Serial.println("      Done setting up Med Reminder v0.1");
    Serial.println();
  }
}
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

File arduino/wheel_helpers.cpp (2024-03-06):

#include "Arduino.h"
#include "constants.h"
#include "alarm_helpers.h"
#include "wheel_helpers.h"

// Define initial states and variables
State currentState = Idle;
int movement_count = 0;
int last_index = 0;  // Initialize to an impossible value for startup detection
int last_is_am = 1;
int last_wheel_number = 0;
int wheel_number = 0;
int current_index = -1;
unsigned long lastDebounceTime = 0;

// Initial setup for wheel sensors
void setupWheel() {
  pinMode(bit1_hall_sensor_pin, INPUT_PULLUP);
  pinMode(bit2_hall_sensor_pin, INPUT_PULLUP);
  pinMode(am_hall_sensor_pin, INPUT_PULLUP);
  pinMode(wheel_hall_sensor_pin, INPUT_PULLUP);

  pinMode(bit1_hall_led_pin, OUTPUT);
  pinMode(bit2_hall_led_pin, OUTPUT);
  pinMode(am_hall_led_pin, OUTPUT);
  pinMode(wheel_hall_led_pin, OUTPUT);
}

int upToDown(int reading) {
  return reading == HIGH ? 0 : 1;
}


void checkDayTime() {

  // Read sensor values
  wheel_number = !digitalRead(wheel_hall_sensor_pin);
  digitalWrite(wheel_hall_led_pin, wheel_number ? HIGH : LOW);

  bool isAM = upToDown(digitalRead(am_hall_sensor_pin));
  digitalWrite(am_hall_led_pin, isAM ? LOW : HIGH);
  setIsAM(isAM);

  int bit1 = upToDown(digitalRead(bit1_hall_sensor_pin));
  int bit2 = upToDown(digitalRead(bit2_hall_sensor_pin));
  digitalWrite(bit1_hall_led_pin, bit1 ? HIGH : LOW);
  digitalWrite(bit2_hall_led_pin, bit2 ? HIGH : LOW);

  current_index = ((bit2 << 1) | (bit1)) + (wheel_number * 3) + 1;
}

int getIndex() {
  checkDayTime();

  // Convert sensor readings to binary index
  return current_index;
}



void printMovement(int spotsMoved, int index, int wheelNumber) {
  // Serial.print("SPOTS MOVED:");
  // Serial.print(spotsMoved);
  // Serial.print(" -> Current Slice: ");
  // Serial.print(index);
  // Serial.print(" -> WHEEL: ");
  // Serial.println(wheelNumber);
  printSystemTime();
  // printDowTod();
}

void printMovement() {
  int index = getIndex();
  int spotsMoved = getMovementCount();
  int wheelNumber = getWheelNumber();
  printMovement(spotsMoved, index, wheelNumber);
}

// Function to handle state transitions
void transitionTo(State newState) {
  // Serial.print("Transitioning from: ");
  // Serial.print(currentState);
  // Serial.print(" -> ");
  // Serial.println(newState);

  currentState = newState;
  switch (currentState) {
    case Idle:
      //Serial.println(" -------------------------------------- IDLE ----------------------------------------");
      movement_count = 0;
      last_wheel_number = wheel_number;
      last_index = getIndex();
      // Setup for Idle state
      break;
    case Debouncing:
       //Serial.println(" -------------------------------------- DEBOUNCEING ----------------------------------------");
      // Serial.println(movement_count);
      lastDebounceTime = millis();
      break;
    case Count_Movement:
      //Serial.println(" -------------------------------------- COUNTING MOVEMENT ----------------------------------------");
      movement_count++;
      break;
    case Waiting_For_More_Movement:
      lastDebounceTime = millis();
      //Serial.println(" -------------------------------------- WAITING FOR MORE MOVEMENT ----------------------------------------");
      last_index == getIndex();
      //debounceTimer = millis();
      break;
    case Movement_Detected:
      //Serial.println(" -------------------------------------- Movement found ----------------------------------------");
      // Actions for movement detected
      break;
  }
}

// Function to check and update the state based on sensor readings
void checkState() {
  // Ensure we're constantly updating the index based on the current sensor state
  int index = getIndex();

  bool movement = false;
  if (millis() > 10000) {
    movement = detectWheelMovement();  // Check if the wheel has moved since the last reading
  }


  if (currentState == Idle) {
    if (movement) {
      transitionTo(Debouncing);
    }
  } else if (currentState == Debouncing) {
    int elapsedTime = (millis() - lastDebounceTime);
    int index = getIndex();
    // Serial.print("Elapsed: ");
    // Serial.println(elapsedTime);
    if ((elapsedTime > wheelTurnDebounceMs)) {
      lastDebounceTime = millis();
      transitionTo(Count_Movement);
    } else {
      if (movement) {
        lastDebounceTime = millis();
        last_index = getIndex();
      }
      // Serial.print("Waiting for elapsed time to expire: ");
      // Serial.println(elapsedTime);
    }
  } else if (currentState == Count_Movement) {
    // Assuming movement count is handled here
    transitionTo(Waiting_For_More_Movement);
    //Serial.println(elapsedTime);
  } else if (currentState == Waiting_For_More_Movement) {
    if ((millis() - lastDebounceTime) > quickTurnThresholdMs) {
      //Serial.println("Moving from Waiting to MOVEMENT DETECTED!!!");
      transitionTo(Movement_Detected);
    } else if (movement) {
      //Serial.println("Moving from Waiting back to debouncing!!!");
      transitionTo(Debouncing);
    }
  } else if (currentState == Movement_Detected) {
    // do nothing until clearMovement() is called...
    // Serial.print("waiting for movement to be cleared() - spots: ");
    // Serial.println(movement_count);
  }
}

int getWheelNumber() {
  return wheel_number;
}

bool movementDetected() {
  return currentState == Movement_Detected;
}

int getMovementCount() {
  return movement_count;
}

bool detectWheelMovement() {
  int wheelNumber = getWheelNumber();
  if (last_wheel_number != wheelNumber) {
    //Serial.println("DETECTED WHEEL CHANGE");
    return true;
  }

  bool isAM = getIsAM();
  if (last_is_am != isAM) {
    //Serial.println("                                                                   AM CHANGE DETECTED");
    //Serial.println("AM/PM CHANGED from " + String(last_is_am) + " to current AM/PM: " + String(isAM));
    last_is_am = isAM;
    return true;
  }

  int index = getIndex();     // Get the current index based on sensor values
  if (last_index != index) {  // Check if there's a change and it's not the initial setup
    //Serial.println("Index Changed: from " + String(last_index) + " to " + String(index));
    return true;
  }
  return false;
}

void clearMovement() {
  //Serial.println("CLEARING MOVEMENT COUNT!");
  movement_count = 0;
  currentState = Idle;      // Reset to Idle after clearing movement
  last_index = getIndex();  // Initialize to an impossible value for startup detection
  last_is_am = getIsAM();
  last_wheel_number = getWheelNumber();
}

void printAndClearMovement() {
  int index = getIndex();
  int spotsMoved = getMovementCount();
  int wheelNumber = getWheelNumber();
  printMovement(spotsMoved, index, wheelNumber);
  // Handle wheel movement (e.g., update state, play confirmation beep)
  clearMovement();
  emitBeepSequence(750, 1);  // Example usage of emitBeepSequence
}

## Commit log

2024-03-01 First pass on medremidner.
    [InsertSlices.scad, InsertSlices.stl]
2024-03-01 Created 3d print to create inserts for the med dispenser.
    [InsertSlices.scad]
2024-03-01 We have code that compiles now.
    [InsertSlices.scad]
2024-03-01 Continued testing - got code mostly working - still have to actually test.
    [InsertSlicesv2.stl]
2024-03-02 Moved code from vscode to android studio and adjusted accordingly. Builds, compiles and deploys. Now it's just about detecting movement and we'll be off to the races.
    [InsertSlices.scad, InsertSlicesv3.stl, InsertSlicesv4.stl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]
2024-03-02 Bump code to test final deployment (before sensors arrive)
2024-03-03 Consistently detects (and reports the current day/time).
2024-03-03 Added buttons and full testing, added tracking for timers.
2024-03-04 Test prints - and increased size of wheel insert.
    [InsertSlices.scad, InsertSlicesv10.stl, InsertSlicesv11.stl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]
2024-03-05 Snapshot - doesn't actually work right now - but we need to get to more regular snapshots.
    [InsertSlices.scad, InsertSlicesv17_1pc.stl, InsertSlicesv18_14pc.stl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]
2024-03-05 Moved renamed arduino from sketch1 to just be arduino.ino.
2024-03-05 Added holder box.
    [CarrierBox.scad, InsertSlices.scad]
2024-03-12 Updated flow charts to work better for the task at hand.
2024-03-18 bump. moving to c++
    [InsertSlices.stl, InsertSlicesv10.stl, InsertSlicesv11.stl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]
2024-03-19 Fully compiles in arduino. Still pretty big.
2024-03-19 Added a second target - arduino to statemachine functions instead of classes.
2024-03-23 added wiring diagram, and made the box big enough for the board.
    [box_v5_no_lid.stl, box_v6_no_lid.stl, box_v7_no_lid.stl]
2024-03-23 Wiring digram basically working. Still needs a little bit of refinement.
2024-03-23 Testing adding additional devices.
2024-03-24 Cleaned up states to more closely match the current state.
2024-03-24 Added wiring diagram to README.md
2024-03-26 Switched to smaller, functional implementation. Compiles, builds, runs at this point - does not yet ingteract with the pins... that's next.
    [Super Jaiks.stl, box_v8_no_lid.stl]
2024-03-27 Clarified BaseState machine behavior, from the custom state machine behavior per FSM. Much clearer separation of concerns.
    [InsertTestSlice_1pc.stl]
2024-03-27 Saved changes.
    [InsertTestSlice_v2_1pc.stl, InsertTestSlice_v3_1pc.stl, InsertTestSlice_v4_1pc.stl]
2024-03-28 First pass - after completely deleting my prototype code. :(
2024-03-28 Got build in line with current tools - compiles runs as expected.
